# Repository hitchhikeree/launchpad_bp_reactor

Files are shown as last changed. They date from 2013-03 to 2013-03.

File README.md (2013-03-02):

Reactor LaunchPad BoosterPack
=========================

3-axis accelerometer, gyroscope, and magnetometer sensors coupled with an IR proximity sensor and RGB color sensor. Useful for robotics, flying drones, and the like.

## Project Links
- <a href="http://www.hitchhikeree.org/reactor/">HitchhikerEE page</a>
- <a href="http://youtu.be/DQJmf79zrzc">YouTube video</a>
- <a href="https://docs.google.com/folder/d/0B5HjtPsFD8u5YVA3ZUJud2s5a2c/edit?usp=sharing">Design files on Google Drive</a>
- <a href="http://e2e.ti.com/group/microcontrollerprojects/m/boosterpackcontest/664830.aspx">LaunchPad BoosterPack Contest page</a>

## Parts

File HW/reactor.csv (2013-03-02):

Qty | Value | Device | Package | Parts | Description | MPN
1 |  | LAUNCHPAD_BOOSTER_PACK | LAUNCHPAD_BOOSTER_PACK | U$1
1 |  | LSM303DLHC | LGA14 | U$7 |  | LSM303DLHC
1 |  | LSM330DLC | LGA28-4X5 | U$8 |  | LSM330DLC
1 |  | LSM333D | LGA28 | U$9 |  | LSM333D
1 |  | TCS32X0 | SOIC8 | U$5 |  | TCS32X0
1 |  | VCNL3020 | VCNL3020 | U$6 |  | VCNL3020
1 | 0.1u | C-EUC0603 | C0603 | C17 | CAPACITOR, European symbol | LMK107BBJ106MALT
8 | 0.1u | C-EUC0603 | C0603 | C2, C3, C6, C9, C10, C14, C15, C19 | CAPACITOR, European symbol | VJ0603V104ZXXCW1BC
2 | 0.22u | C-EUC0603 | C0603 | C7, C11 | CAPACITOR, European symbol | VJ0603V224MXJPW1BC
3 | 10K | R-US_R0603 | R0603 | R3, R7, R8 | RESISTOR, American symbol | WR06X1002FTL
2 | 10K, DNI | R-US_R0603 | R0603 | R9, R10 | RESISTOR, American symbol | WR06X1002FTL
1 | 10n | C-EUC0603 | C0603 | C16 | CAPACITOR, European symbol | VJ0603Y103KXACW1BC
4 | 10u | C-EUC0603 | C0603 | C4, C8, C13, C18 | CAPACITOR, European symbol | LMK107BBJ106MALT
15 | 33 | R-US_R0603 | R0603 | R4, R5, R6, R11, R12, R13, R14, R15, R16, R17, R18, R19, R20, R21, R22 | RESISTOR, American symbol | CR0402-JW-330GLF
2 | 4.7u | C-EUC0603 | C0603 | C5, C12 | CAPACITOR, European symbol | GRM188F51A475ZE20J
2 | 5.6K, 5% | R-US_R0603 | R0603 | R1, R2 | RESISTOR, American symbol | RK73B1JTTDD562J

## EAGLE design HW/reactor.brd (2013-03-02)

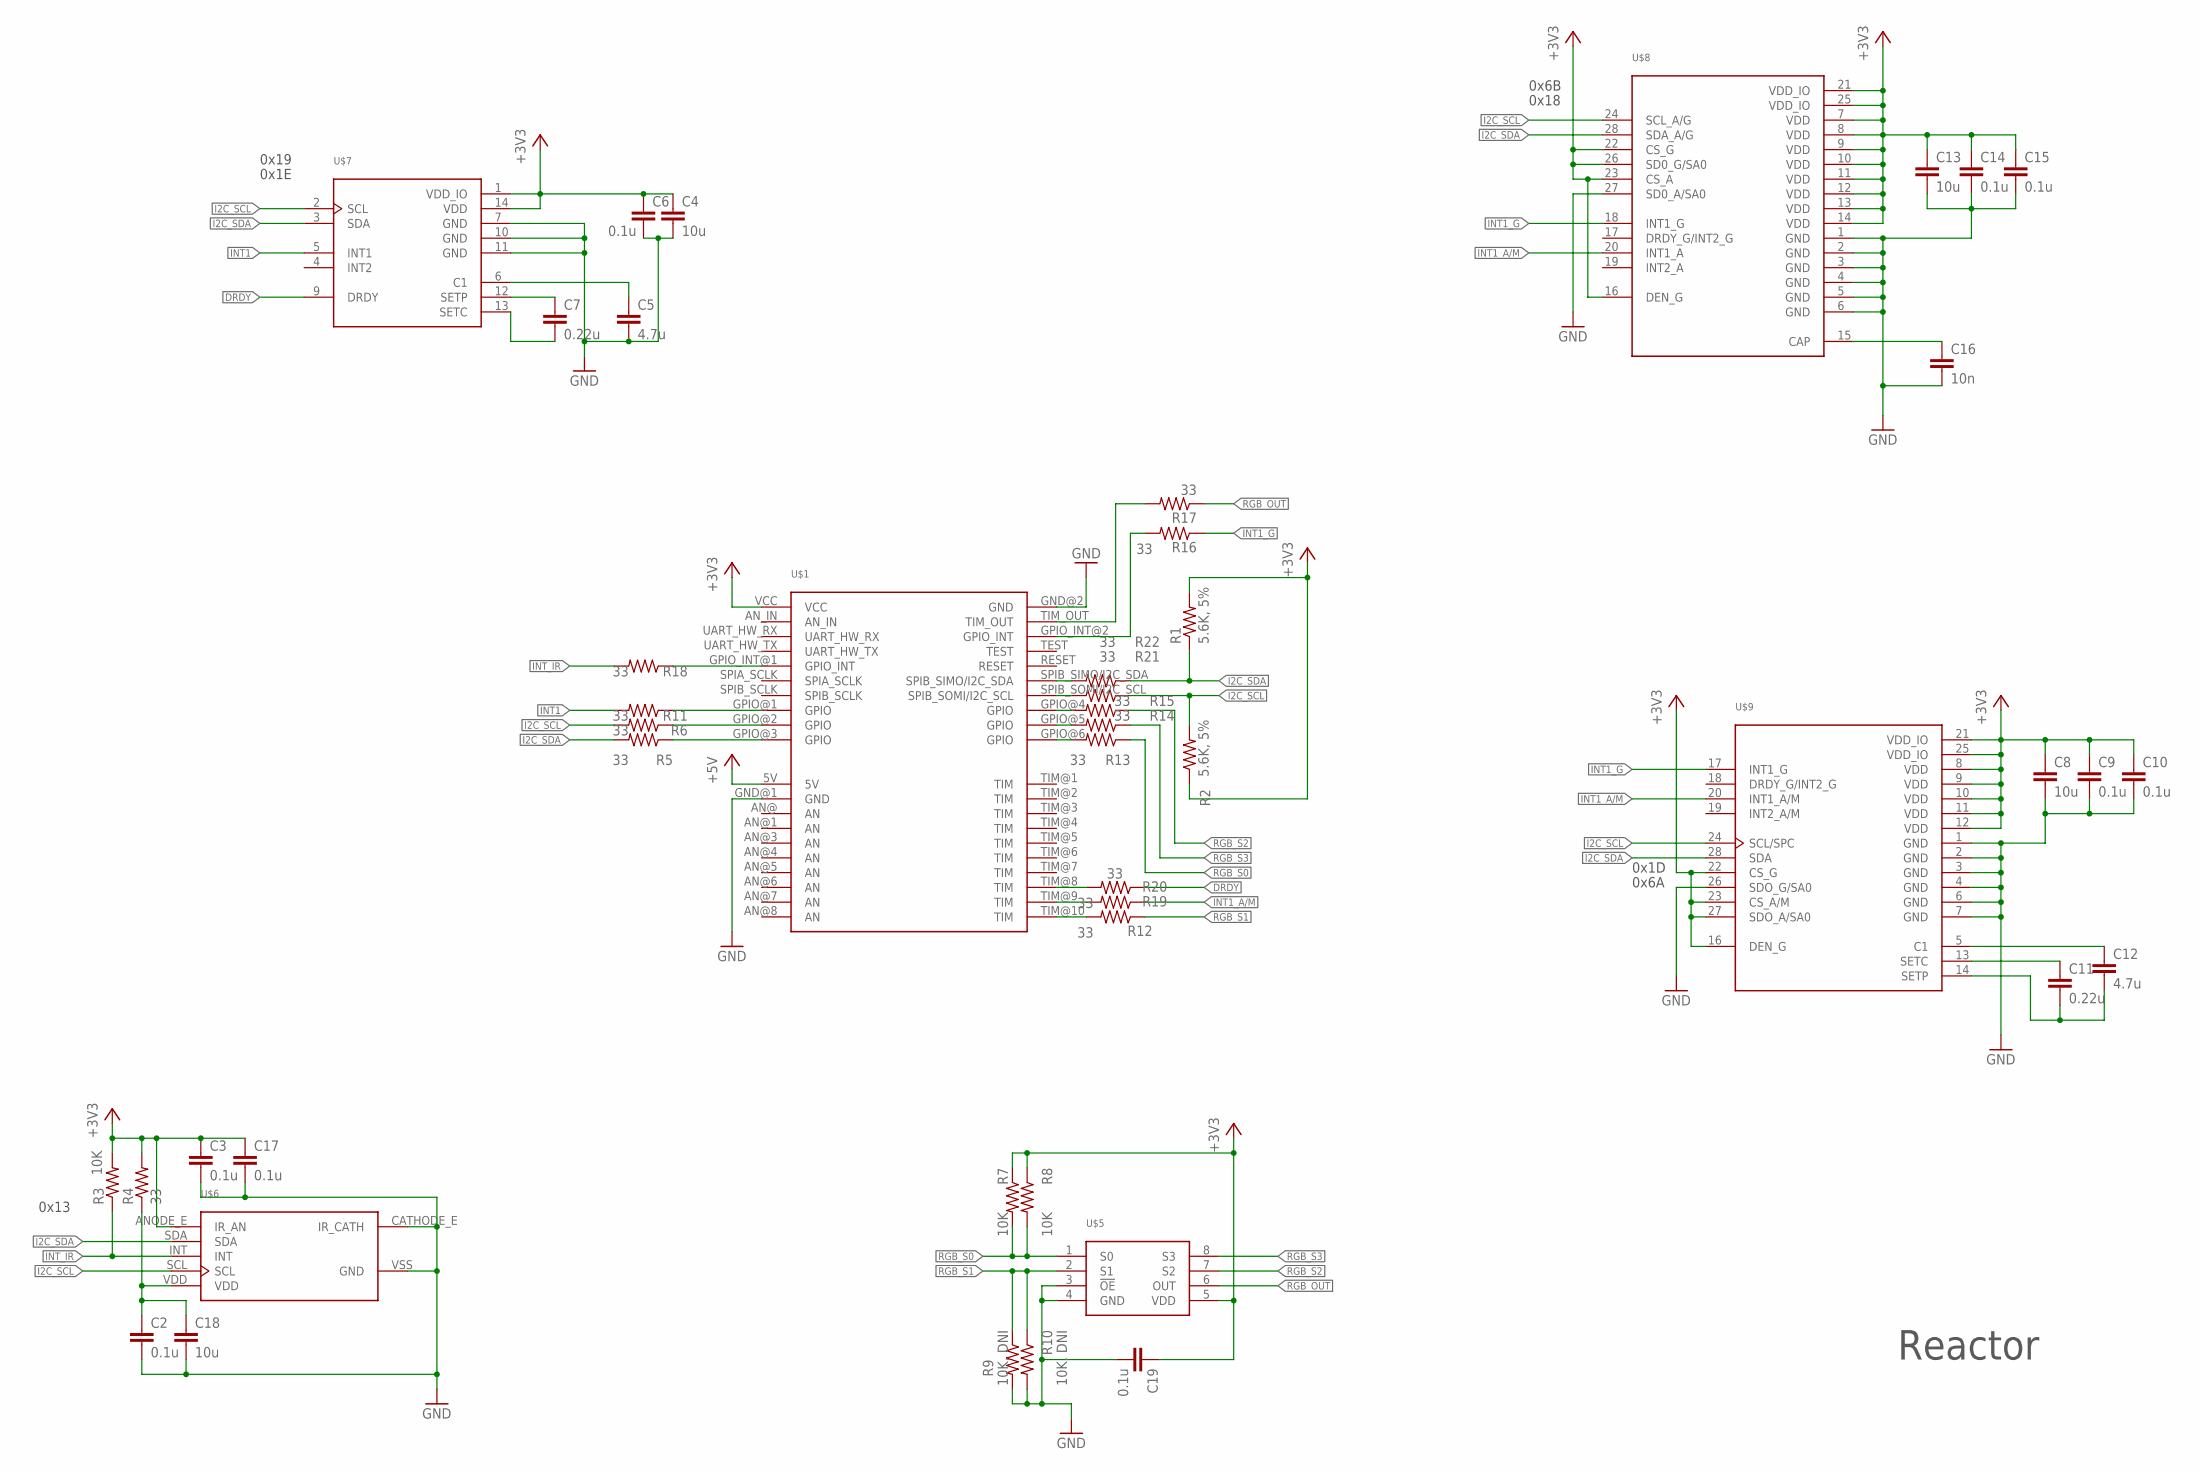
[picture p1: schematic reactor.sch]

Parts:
C2, C3, C6, C9, C10, C14, C15, C19: 0.1u; C0603; MPN VJ0603V104ZXXCW1BC
C4, C8, C13, C18: 10u; C0603; MPN LMK107BBJ106MALT
C5, C12: 4.7u; C0603; MPN GRM188F51A475ZE20J
C7, C11: 0.22u; C0603; MPN VJ0603V224MXJPW1BC
C16: 10n; C0603; MPN VJ0603Y103KXACW1BC
C17: 0.1u; C0603; MPN LMK107BBJ106MALT
R1, R2: 5.6K, 5%; R0603; MPN RK73B1JTTDD562J
R3, R7, R8: 10K; R0603; MPN WR06X1002FTL
R4, R5, R6, R11, R12, R13, R14, R15, R16, R17, R18, R19, R20, R21, R22: 33; R0603; MPN CR0402-JW-330GLF
R9, R10: 10K, DNI; R0603; MPN WR06X1002FTL
U$1: LAUNCHPAD_BOOSTER_PACK
U$5: TCS32X0; SOIC8; MPN TCS32X0
U$6: VCNL3020; MPN VCNL3020
U$7: LSM303DLHC; LGA14; MPN LSM303DLHC
U$8: LSM330DLC; LGA28-4X5; MPN LSM330DLC
U$9: LSM333D; LGA28; MPN LSM333D

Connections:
+3V3: C3.1, C4.1, C6.1, C8.1, C9.1, C10.1, C13.1, C14.1, C15.1, C17.1, C19.1, R1.2, R2.1, R3.2, R4.2, R7.1, R8.1, U$1.VCC, U$5.5 (VDD), U$6.ANODE_E (IR_AN), U$7.1 (VDD_IO), U$7.14 (VDD), U$8.7 (VDD), U$8.8 (VDD), U$8.9 (VDD), U$8.10 (VDD), U$8.11 (VDD), U$8.12 (VDD), U$8.13 (VDD), U$8.14 (VDD), U$8.16 (DEN_G), U$8.21 (VDD_IO), U$8.22 (CS_G), U$8.23 (CS_A), U$8.25 (VDD_IO), U$8.26 (SD0_G/SA0), U$9.8 (VDD), U$9.9 (VDD), U$9.10 (VDD), U$9.11 (VDD), U$9.12 (VDD), U$9.16 (DEN_G), U$9.21 (VDD_IO), U$9.22 (CS_G), U$9.23 (CS_A/M), U$9.25 (VDD_IO), U$9.27 (SDO_A/SA0)
+5V: U$1.5V
DRDY: R20.1, U$7.9 (DRDY)
GND: C2.2, C3.2, C4.2, C5.2, C6.2, C8.2, C9.2, C10.2, C13.2, C14.2, C15.2, C16.2, C17.2, C18.2, C19.2, R9.2, R10.2, U$1.GND@1 (GND), U$1.GND@2 (GND), U$5.3 (!OE), U$5.4 (GND), U$6.CATHODE_E (IR_CATH), U$6.VSS (GND), U$7.7 (GND), U$7.10 (GND), U$7.11 (GND), U$8.1 (GND), U$8.2 (GND), U$8.3 (GND), U$8.4 (GND), U$8.5 (GND), U$8.6 (GND), U$8.27 (SD0_A/SA0), U$9.1 (GND), U$9.2 (GND), U$9.3 (GND), U$9.4 (GND), U$9.6 (GND), U$9.7 (GND), U$9.26 (SDO_G/SA0)
I2C_SCL: R2.2, R6.2, R21.1, U$6.SCL, U$7.2 (SCL), U$8.24 (SCL_A/G), U$9.24 (SCL/SPC)
I2C_SDA: R1.1, R5.2, R22.1, U$6.SDA, U$7.3 (SDA), U$8.28 (SDA_A/G), U$9.28 (SDA)
INT1: R11.2, U$7.5 (INT1)
INT1_A/M: R19.1, U$8.20 (INT1_A), U$9.20 (INT1_A/M)
INT1_G: R16.1, U$8.18 (INT1_G), U$9.17 (INT1_G)
INT_IR: R3.1, R18.2, U$6.INT
unnamed: C2.1, C18.1, R4.1, U$6.VDD
unnamed: R18.1, U$1.GPIO_INT@1 (GPIO_INT)
unnamed: R11.1, U$1.GPIO@1 (GPIO)
unnamed: R19.2, U$1.TIM@9 (TIM)
unnamed: R20.2, U$1.TIM@8 (TIM)
unnamed: R6.1, U$1.GPIO@2 (GPIO)
unnamed: R5.1, U$1.GPIO@3 (GPIO)
unnamed: R21.2, U$1.SPIB_SOMI/I2C_SCL
unnamed: R22.2, U$1.SPIB_SIMO/I2C_SDA
unnamed: R12.2, U$1.TIM@10 (TIM)
unnamed: R15.2, U$1.GPIO@4 (GPIO)
unnamed: R14.2, U$1.GPIO@5 (GPIO)
unnamed: R13.2, U$1.GPIO@6 (GPIO)
unnamed: R17.2, U$1.TIM_OUT
unnamed: R16.2, U$1.GPIO_INT@2 (GPIO_INT)
unnamed: C7.1, U$7.12 (SETP)
unnamed: C7.2, U$7.13 (SETC)
unnamed: C5.1, U$7.6 (C1)
unnamed: C16.1, U$8.15 (CAP)
unnamed: C11.1, U$9.13 (SETC)
unnamed: C11.2, C12.2, U$9.14 (SETP)
unnamed: C12.1, U$9.5 (C1)
RGB_OUT: R17.1, U$5.6 (OUT)
RGB_S0: R7.2, R8.2, R13.1, U$5.1 (S0)
RGB_S1: R9.1, R10.1, R12.1, U$5.2 (S1)
RGB_S2: R15.1, U$5.7 (S2)
RGB_S3: R14.1, U$5.8 (S3)

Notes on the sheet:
Reactor
0x19
0x1E
0x18
0x6B
0x1D
0x6A
0x13

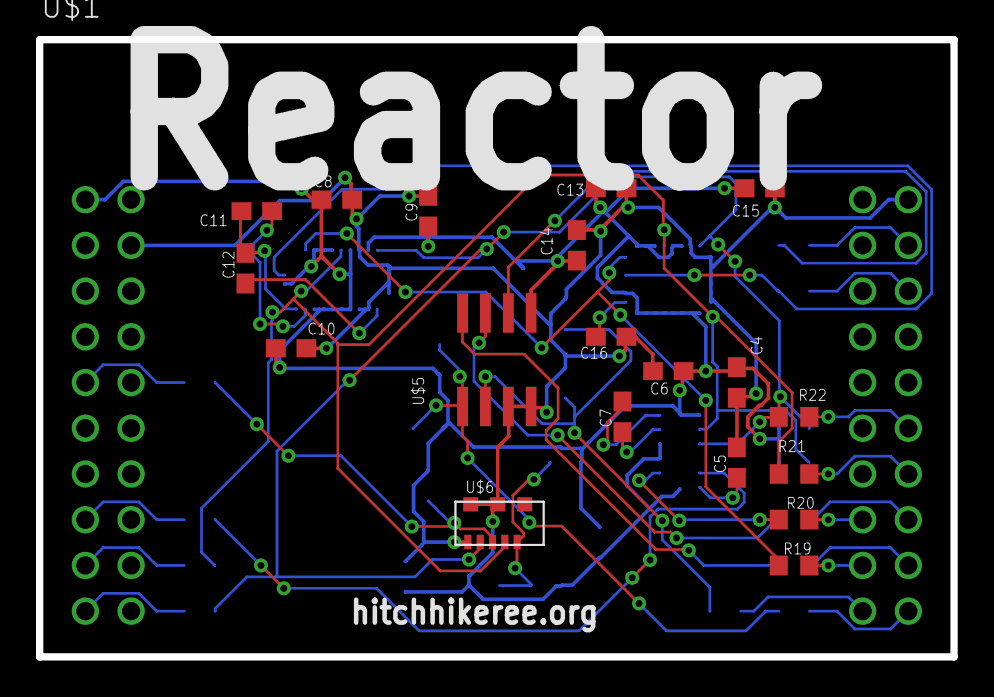
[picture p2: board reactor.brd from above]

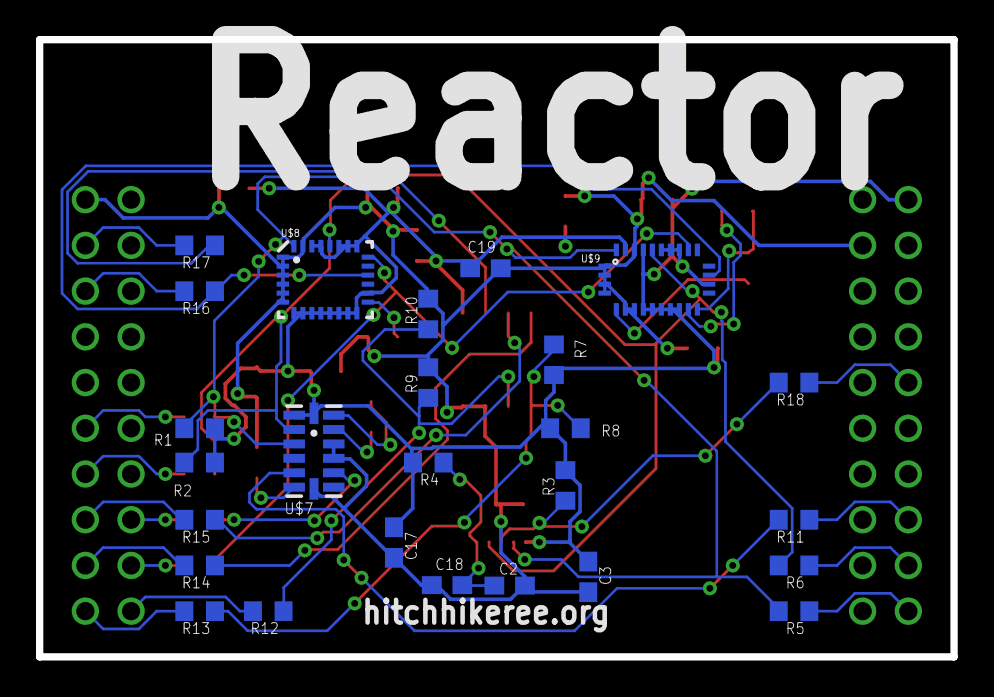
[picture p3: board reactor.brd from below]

Board: 2 copper layers, 50.8 x 34.3 mm, 46 parts (26 on the bottom side), 36 nets.

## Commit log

2013-02-24 Adding base CAD files
    [base.csv, reactor.brd, reactor.sch]
2013-03-02 Finished design
    [base.csv, reactor.brd, reactor.csv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]
